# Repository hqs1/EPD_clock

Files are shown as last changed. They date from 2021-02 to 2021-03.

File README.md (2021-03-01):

# EPD_clock

# 前言

	本作品使用的是涂鸦智能MCU SDK进行开发，MCU使用的是ST家的STM32L051K8U6~~还好这颗MCU现在价格还能接受,模组的话考虑到做低功耗则使用的是ZigBee模组,屏幕使用的是HINK的2.13寸墨水屏(微雪家2.13寸黑白同款),当然这个作品必要得有涂鸦智能网关才能使用。

# 元件选型

| 功能 | 型号 |
| --- | --- |
| 单片机 | STM32L051K8U6 |
| 温湿度传感器 | SHT30 |
| ZigBee模组 | TYZS3 |
| LDO | HT7333 |
| 充电芯片 | TP4057 |
| SPI Flash | MX25L1006EZUI |
| 墨水屏 | E0213A04 |

# 基本功能

1. 时间显示，每分钟刷新(24小时自动联网校时)
2. 温湿度显示，半小时刷新并且上报云端
3. 可通过涂鸦智能平台实现设备自动化和断网自动化
4. 可通过涂鸦智能平台实现OTA功能

# 成品效果



# 低功耗

	这个作品大部分时间都花在扣功耗上，使用了4颗PMOS分别控制SPI FLASH、墨水屏、模组和电池电压测量电路。在不需要使用对应的器件时，关断电源减少不必要的功耗。
	MCU通过RTC闹钟唤醒，初始化SPI和必要的GPIO并且刷新屏幕更新时间，当更新完成MCU将GPIO设置为模拟输入，减少不必要的功耗。目前休眠电流能压在平均35ua左右(模组长通电情况下)。

  当然这个电流还能压，如果控制模组电源则休眠电流能压到2.7-3ua。(LDO静态电流+SHT30+MCU休眠电流)

# 外壳

	外壳使用的是fusion 360进行绘制的，PCB模型因为现在立创EDA暂时还不能导出step的文件模型，所以这里临时采用Altium Designer进行导出。
稍微渲染一下的效果
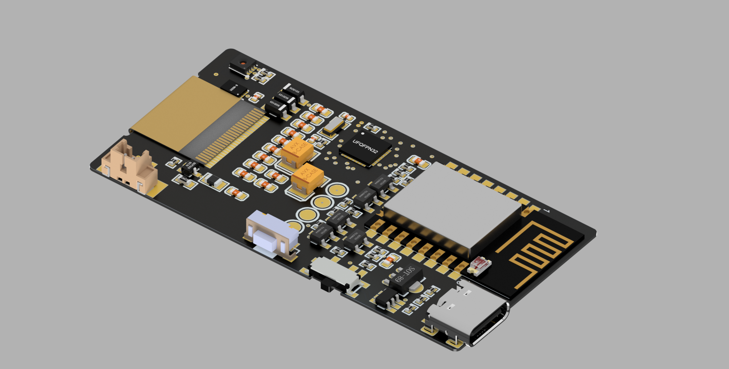
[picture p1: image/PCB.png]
PCB V3 v11.png

有了PCB模型画外壳就事半功倍了，至少不用卡尺量PCB。
外壳成品图
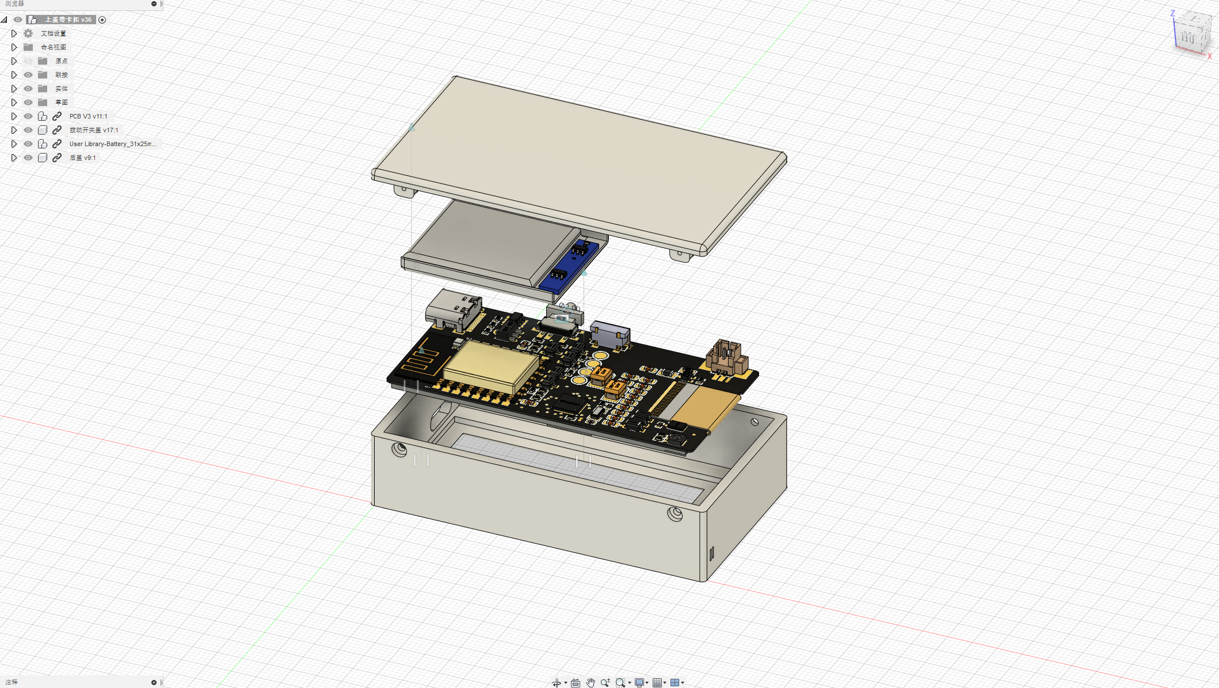
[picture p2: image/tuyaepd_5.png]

渲染一下的效果
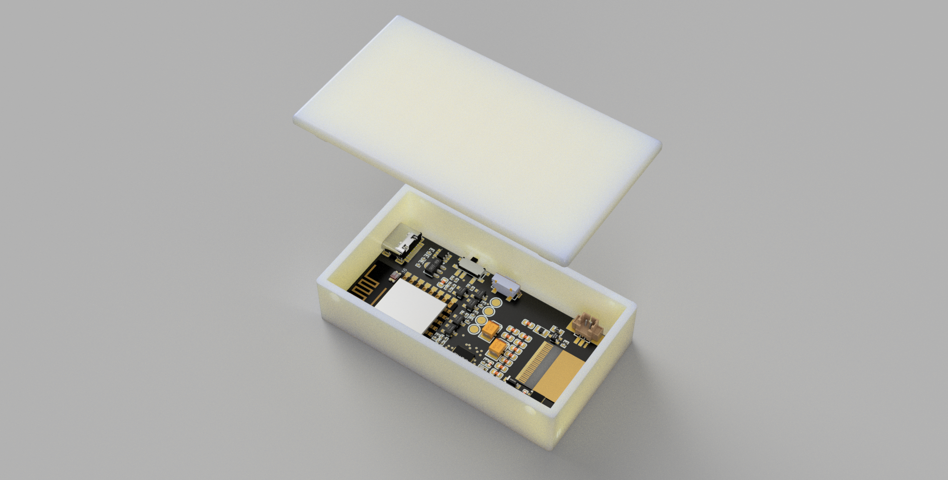
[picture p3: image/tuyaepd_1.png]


实体装配后


# 作品演示

[https://www.bilibili.com/video/BV1Pz4y117Rv](https://www.bilibili.com/video/BV1Pz4y117Rv)

# 立创EDA
[https://lceda.cn/hqs1/epd_clock](https://lceda.cn/hqs1/epd_clock)

# 后期玩法

本作品PCB是兼容涂鸦智能WIFI模组，可以焊WIFI模组移植涂鸦WIFI MCU SDK在该PCB上使用，并且可实现天气显示在墨水屏。**有任何商用，或牟利想法的，请离开！！！开源不是白嫖。请自主学习，共同成长。**

# 支持作者
	点个Star吧,呜呜呜

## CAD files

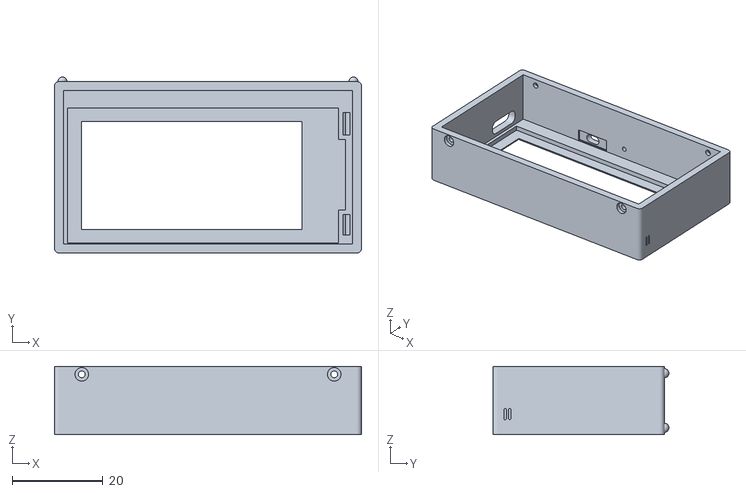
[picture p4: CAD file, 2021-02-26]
3D Model/上盖带卡扣.stl
67.5 x 38.7 x 15.0

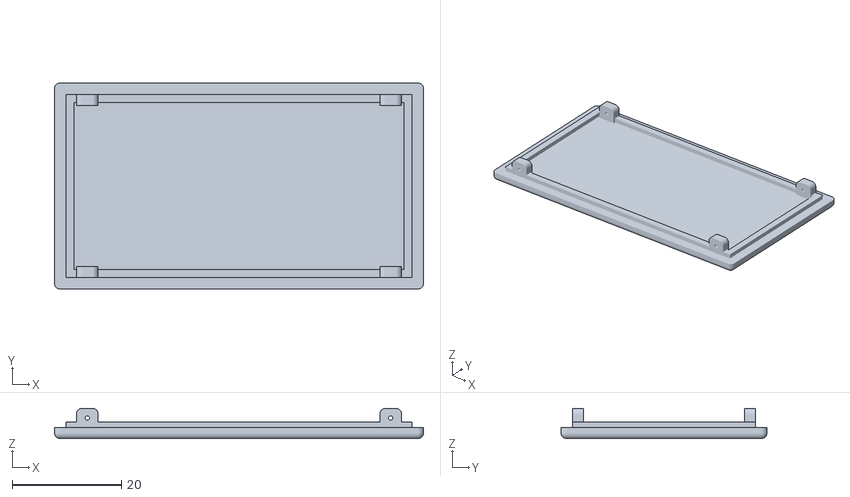
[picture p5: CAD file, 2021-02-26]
3D Model/后盖.stl
67.5 x 37.7 x 5.50

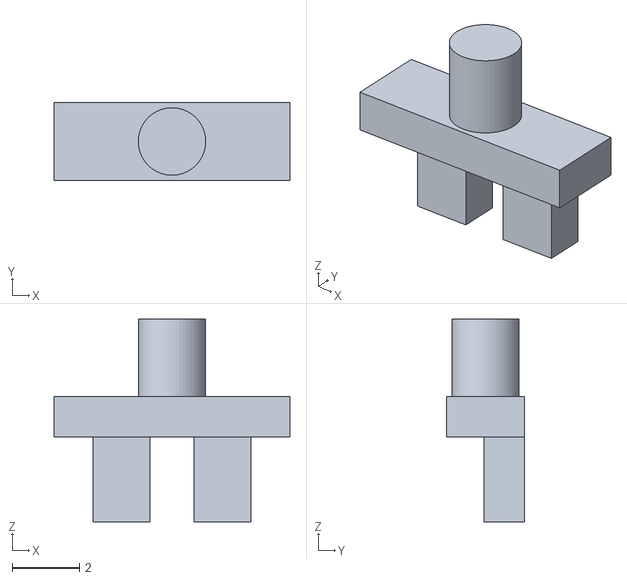
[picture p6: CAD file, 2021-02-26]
3D Model/拨动开关盖.stl
7.00 x 2.30 x 6.02

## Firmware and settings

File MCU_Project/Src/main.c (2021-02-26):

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

/* Includes ------------------------------------------------------------------*/
#include "main.h"
#include "adc.h"
#include "i2c.h"
#include "rtc.h"
#include "spi.h"
#include "tim.h"
#include "usart.h"
#include "gpio.h"

/* USER CODE BEGIN Includes */
#include "zigbee.h"
#include "sht30.h"
#include "gui.h"
#include "Battery.h"
#include "app.h"

/* USER CODE END Includes */


void SystemClock_Config(void);
/* USER CODE BEGIN 0 */
APP_T app_data;
/* USER CODE END 0 */

/**
  * @brief  The application entry point.
  * @retval int
  */
int main(void)
{
  /* MCU Configuration--------------------------------------------------------*/

  /* Reset of all peripherals, Initializes the Flash interface and the Systick. */
  HAL_Init();

  /* Configure the system clock */
  SystemClock_Config();

  /* Initialize all configured peripherals */
  MX_GPIO_Init();
  MX_ADC_Init();
  MX_I2C1_Init();
  MX_RTC_Init();
  MX_SPI1_Init();
  MX_USART1_UART_Init();
  MX_TIM6_Init();
  /* USER CODE BEGIN 2 */
  __HAL_UART_ENABLE_IT(&huart1, UART_IT_RXNE);
  HAL_TIM_Base_Start_IT(&htim6);
  APP_Init(&app_data);
  APP_Check_Hardware();
  zigbee_protocol_init();
  
#ifdef SWD_DEBUG
  HAL_DBGMCU_EnableDBGStopMode();
#endif
  /* USER CODE END 2 */

  /* Infinite loop */
  /* USER CODE BEGIN WHILE */
  while (1)
  {
    zigbee_uart_service();
    APP_Serve(&app_data);
    /* USER CODE END WHILE */

    /* USER CODE BEGIN 3 */
  }
  /* USER CODE END 3 */
}

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
/* USER CODE BEGIN 4 */
void HAL_RTC_AlarmAEventCallback(RTC_HandleTypeDef *hrtc)
{
  app_data.app_exit = MCU_WAKEUP_RTC;
  /* Clear Wake Up Flag */
  __HAL_PWR_CLEAR_FLAG(PWR_FLAG_WU);
}

void HAL_GPIO_EXTI_Callback(uint16_t GPIO_Pin)
{
  if (GPIO_Pin == USB_IN_Pin)
  {
    app_data.app_exit = MCU_WAKEUP_USB;
  }
  else if (GPIO_Pin == MCU_WAKEUP_Pin)
  {
    app_data.app_exit = MCU_WAKEUP_SOC;
  }
  else if (GPIO_Pin == BUTTON_Pin)
  {
    app_data.app_exit = MCU_WAKEUP_BTN;
  }

  /* Clear Wake Up Flag */
  __HAL_PWR_CLEAR_FLAG(PWR_FLAG_WU);
}
/* USER CODE END 4 */
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


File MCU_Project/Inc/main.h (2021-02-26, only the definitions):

#define FLASH_CS_Pin GPIO_PIN_1
#define FLASH_CS_GPIO_Port GPIOA
#define EPD_CS_Pin GPIO_PIN_2
#define EPD_CS_GPIO_Port GPIOA
#define EPD_RST_Pin GPIO_PIN_3
#define EPD_RST_GPIO_Port GPIOA
#define EPD_DC_Pin GPIO_PIN_4
#define EPD_DC_GPIO_Port GPIOA
#define EDP_BUSY_Pin GPIO_PIN_0
#define EDP_BUSY_GPIO_Port GPIOB
#define EPD_EN_Pin GPIO_PIN_1
#define EPD_EN_GPIO_Port GPIOB
#define ZIGBEE_EN_Pin GPIO_PIN_2
#define ZIGBEE_EN_GPIO_Port GPIOB
#define ZIGBEE_WAKEUP_Pin GPIO_PIN_8
#define ZIGBEE_WAKEUP_GPIO_Port GPIOA
#define USB_IN_Pin GPIO_PIN_11
#define USB_IN_GPIO_Port GPIOA
#define USB_IN_EXTI_IRQn EXTI4_15_IRQn
#define CHRG_IN_Pin GPIO_PIN_12
#define CHRG_IN_GPIO_Port GPIOA
#define MCU_WAKEUP_Pin GPIO_PIN_15
#define MCU_WAKEUP_GPIO_Port GPIOA
#define MCU_WAKEUP_EXTI_IRQn EXTI4_15_IRQn
#define ADC_EN_Pin GPIO_PIN_3
#define ADC_EN_GPIO_Port GPIOB
#define BUTTON_Pin GPIO_PIN_4
#define BUTTON_GPIO_Port GPIOB
#define BUTTON_EXTI_IRQn EXTI4_15_IRQn
#define FLASH_EN_Pin GPIO_PIN_5
#define FLASH_EN_GPIO_Port GPIOB

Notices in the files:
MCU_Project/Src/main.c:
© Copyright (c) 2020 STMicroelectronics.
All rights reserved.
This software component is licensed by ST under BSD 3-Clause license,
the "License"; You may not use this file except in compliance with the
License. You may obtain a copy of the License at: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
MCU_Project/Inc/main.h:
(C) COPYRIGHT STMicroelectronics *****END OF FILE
